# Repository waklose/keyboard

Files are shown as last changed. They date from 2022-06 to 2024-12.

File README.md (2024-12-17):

# keyboard
This is a repository for my keyboard project. Hardware design and 3D design are both self-taught, so the first designs might leave something to be desired.

## Motivation
The motivation behind making my own keyboard was the fact that I didn't have a keyboard. And I wanted a keyboard :) In retrospect buying a keyboard would actually have been quite a lot cheaper, however there was a specific feature I wanted in my keyboard. This feature relates to the use of the thumb. In normal keyboard both thumbs are primarily used on a single button, namely the space bar. This seems a tad wasteful considering the impressive dexterity of the thumb. When using our phones on the other hand we use the thumbs for the entire keyboard. Furthermore the thumbs are pressed down sideways when pressing the space bar. A more natural usage of the thumb is pressing it inward toward the hand. This is not easily achieved in a normal keyboard, but one can take inspiration from mouses with thumb buttons. As these utilize the thumb in a more natural way without compromising the other fingers. The goal with this project is to make a keyboard that utilizes the entire hand in an efficient and comfortable way. Mostly this will entail creating a design with a natural responsibility and usage of the thumb, while keeping standard usage of the rest of the hand.

## v1
This is a onehanded ergonomical hotswappable mechanical keyboard. Lots of nice adjectives, but the onehanded part is the most important. The result turned out a little bit clunky and a little unpolished, but it got the job done. More details in the dedicated folder.

## v2
Intended Additions/improvements are: backlighting, integrated microcontroller, more comfortable design, better looking design.

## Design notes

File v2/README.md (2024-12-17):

# v2
Additions/improvements are going to be: backlighting, integrated microcontroller, more comfortable design, better looking design. 

## Choice of components
* STM32F072VBT6: This is the microchip I want to use. The choice was inspired by [this](https://github.com/KoBussLLC/grabert-hardware) tutorial. The important part is that it has 87 I/Os and it has a 48 MHz internal oscillator. Thus a keyboard matrix with diodes and an external oscillator is not neccesary, which reduces the amount of components on the pcb.
* WS2812B-2020: This is the RGB LED I will use for the keyboard backlighting. There was tree main reasons for choosing this component. The first reason is the fact that it has an integrated decoupling capacitor, which reduces the amount of components on the pcb. The second reason is that it is an intelligent control LED which means that all LEDs can be controlled by a single port on the microcontroller. Lastly the input voltage on this chip can be as low as 2.7V. Which works very well with the chosen STM32F072VBT6 chip that normally uses VDD=3.3V.

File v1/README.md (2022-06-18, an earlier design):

# v1
This is my first attempt at making a onehanded keyboard. It mostly worked as expected, see [Bugs](#Bugs). 

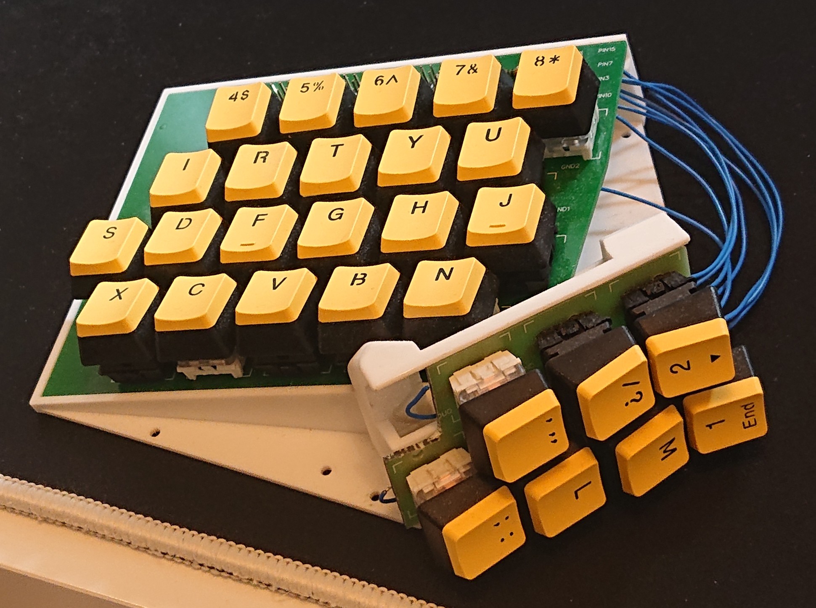
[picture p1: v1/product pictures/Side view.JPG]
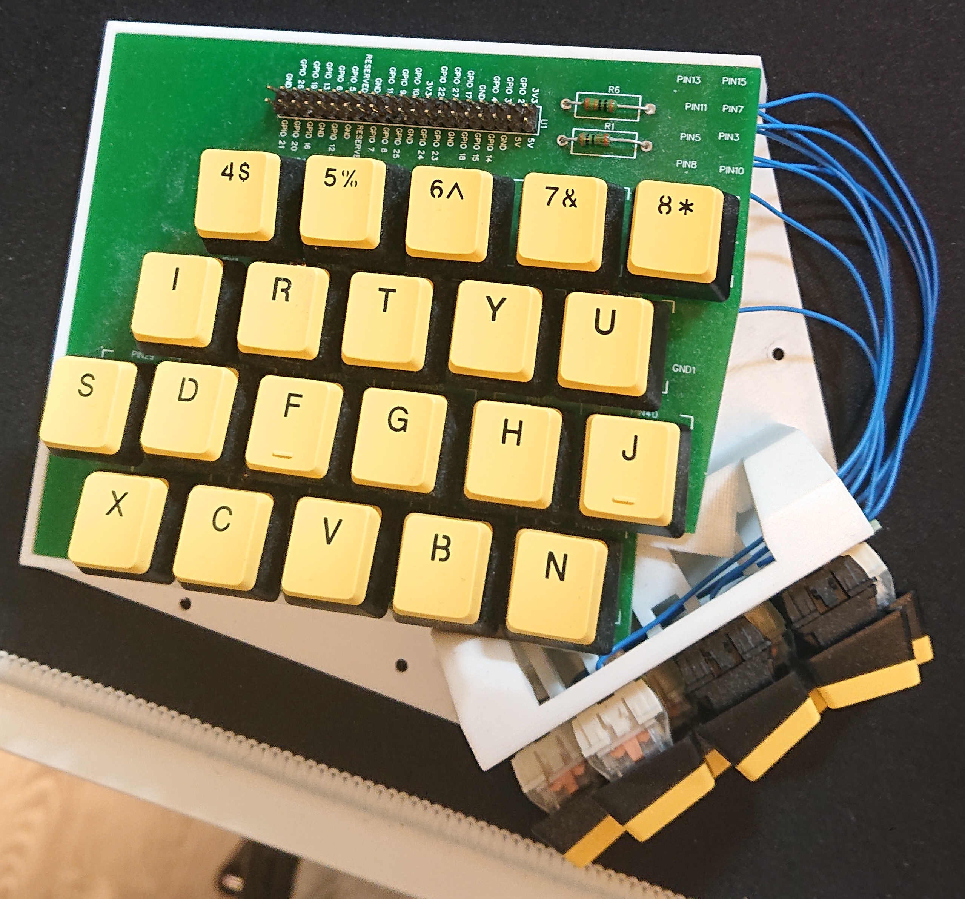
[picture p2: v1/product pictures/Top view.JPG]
 

## frame
3D objects and corresponding gcode files for case and plate are in the folder *frame*. *Fusion 360* and *PrusaSlicer* was used to design these. The print was produced at [*Omega Verksted*](https://www.omegav.ntnu.no/) at NTNU.

## pcb
The pcb and corresponding schematic are in the *pcb* folder. *EasyEDA* was used to create these. 
The pcb was ordered from [JLCPCB](https://jlcpcb.com/), and the components and connections were soldered by hand.

## Code
* The raspberry pi 4 was configured as a keyboard using [this](https://randomnerdtutorials.com/raspberry-pi-zero-usb-keyboard-hid/) online tutorial.
* The code was written in python and it is not appended. It was a very simple while true loop. It did not handle *switch bounce* in any way, however this did not turn out to be a problem.

## Choice of components
* **Raspberry pi 4**: A small computer in and of itself, so it's definitely way stronger than needed. I used it simply because I had one at hand, and it is connected to the pcb via a flat cable so it can still be disconnected and used for other projects. A simple microcontroller such as the *Arduino Pro Micro* would be a more reasonable choice. However the microchip (ATmega32U4) has fewer gpio ports and would require me to make a standard keyboard matrix. Which would require a diode for every switch in order to avoid ghosting. It seemed simpler use a controller with more gpio ports.
* **Kailh hotswap sockets**: In order to make the keyboard hotswappable, such that switches easily can be changed.
* **Cherry mx silver / Cherry mx red / Kailh silver**: These are the different switches I used. Kailh silver and Cherry mx silver are very similar and was used interchangeably. All of them are linear switches. The silver switches has quite short pre travel, which in some cases caused misclicks on the buttons where my fingers rested. Thus I used cherry mx red on these buttons instead.
* **1k resistor**: in order to protect the raspberry pi from a short in the case of faulty code.

## Bugs
* **Button not working properly**: The button connected to GPIO 2 only works a part of the time. This is likely because of a slight oversight on my part. Both GPIO 2 and 3 are pysically connected to 1.8k unchangable pull-up resistors, which are lower values than the default. This is problematic because pressing the switch creates a connection to ground with a 1k resistor (which was added for protection). Thus it is definetely closer to logical zero but still not sufficiently close to work consistently. A possible fix is to remove or reduce the 1k resistor.

## Improvements
* **Comfortable thumb buttons**: The angles of the case were not the most comfortable. A big part of the problem was that pressing the thumb buttons sideways resulted in a sideways force, which resulted in displacement and/ord rotation of the keyboard. The thumb buttons could also have had angles closer to 90 degree along the xy-axis.
* **Comfortable hand position**: A wrist rest could be integrated into the case.
* **General design**: The design ended up looking very clunky and it was also very impractical to move around. The main problem is the fact that the raspberry pi 4 is connected to the keyboard via a flat cable. Adding a microchip to the pcb is the obvious solution.

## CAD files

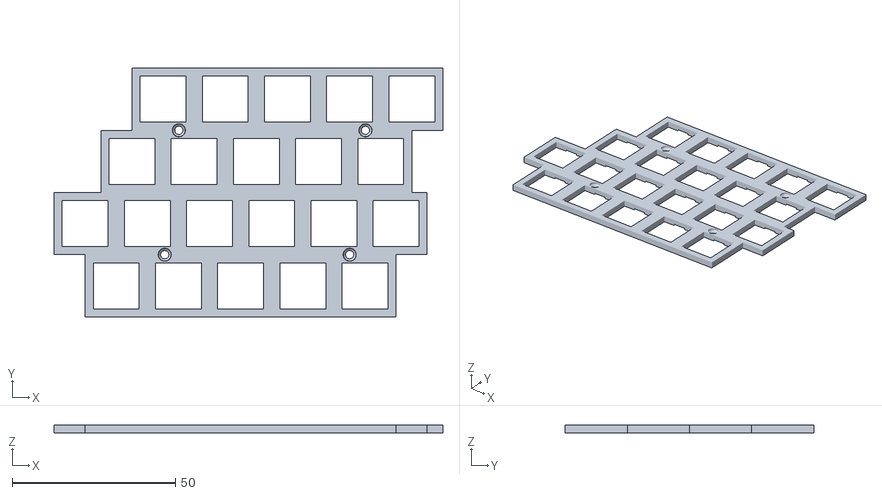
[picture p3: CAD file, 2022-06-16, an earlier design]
v1/frame/plate_main.stl
119.1 x 76.2 x 2.40

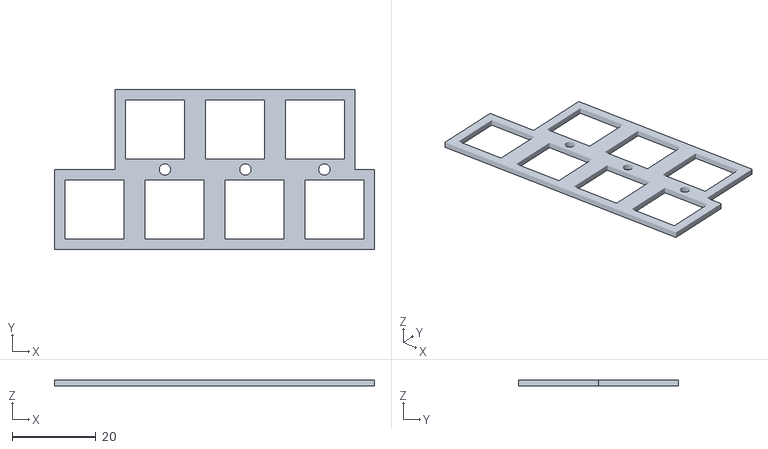
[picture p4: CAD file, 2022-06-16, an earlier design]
v1/frame/plate_thumbButtons.stl
76.2 x 38.1 x 1.50

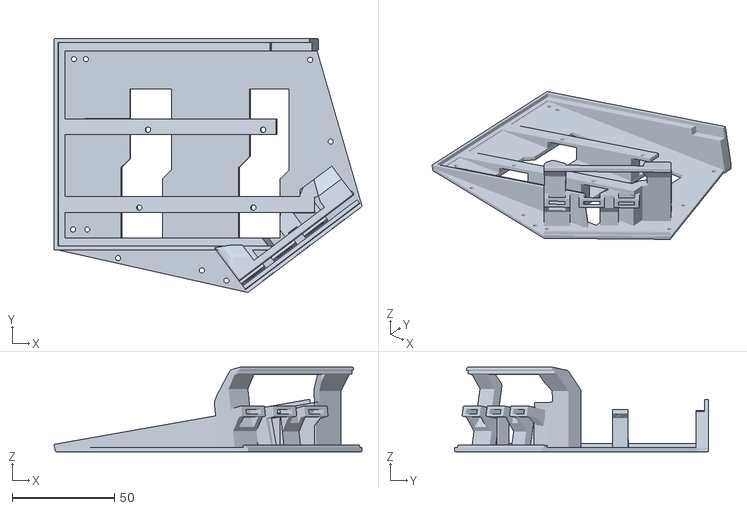
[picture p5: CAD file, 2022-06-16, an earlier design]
v1/frame/case.stl
150.6 x 124.2 x 41.3

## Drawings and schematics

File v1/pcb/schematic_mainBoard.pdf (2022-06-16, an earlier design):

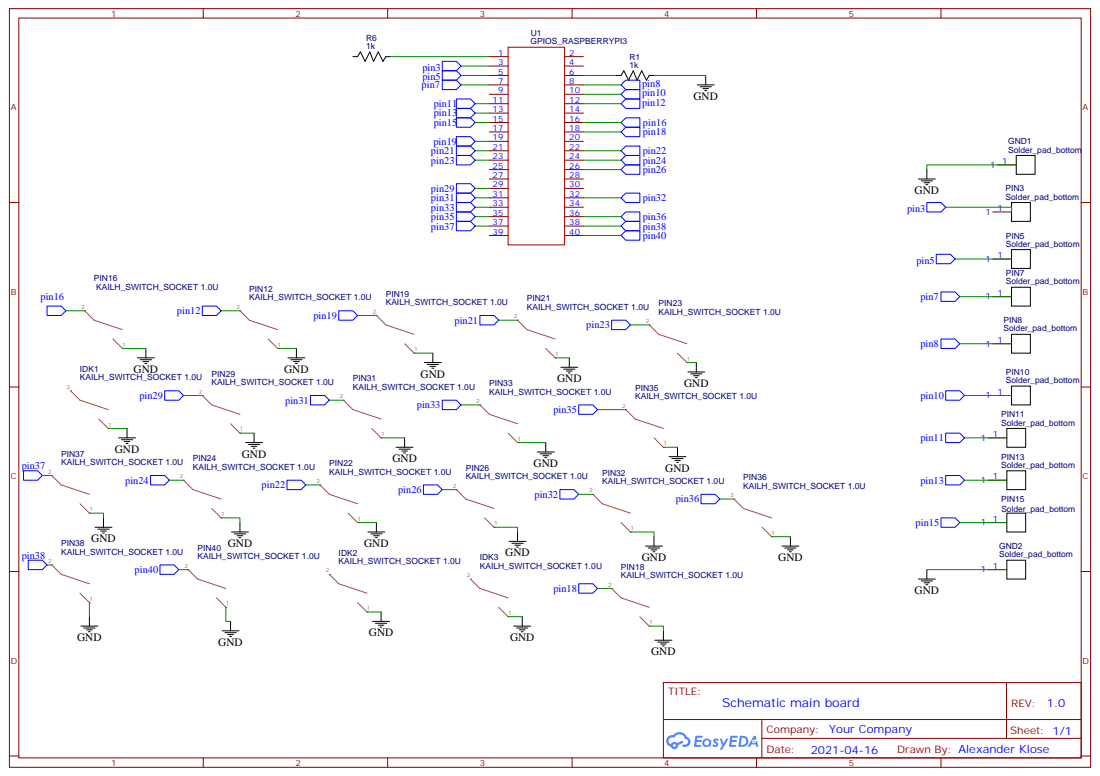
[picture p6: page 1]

Drawn By: Alexander Klose

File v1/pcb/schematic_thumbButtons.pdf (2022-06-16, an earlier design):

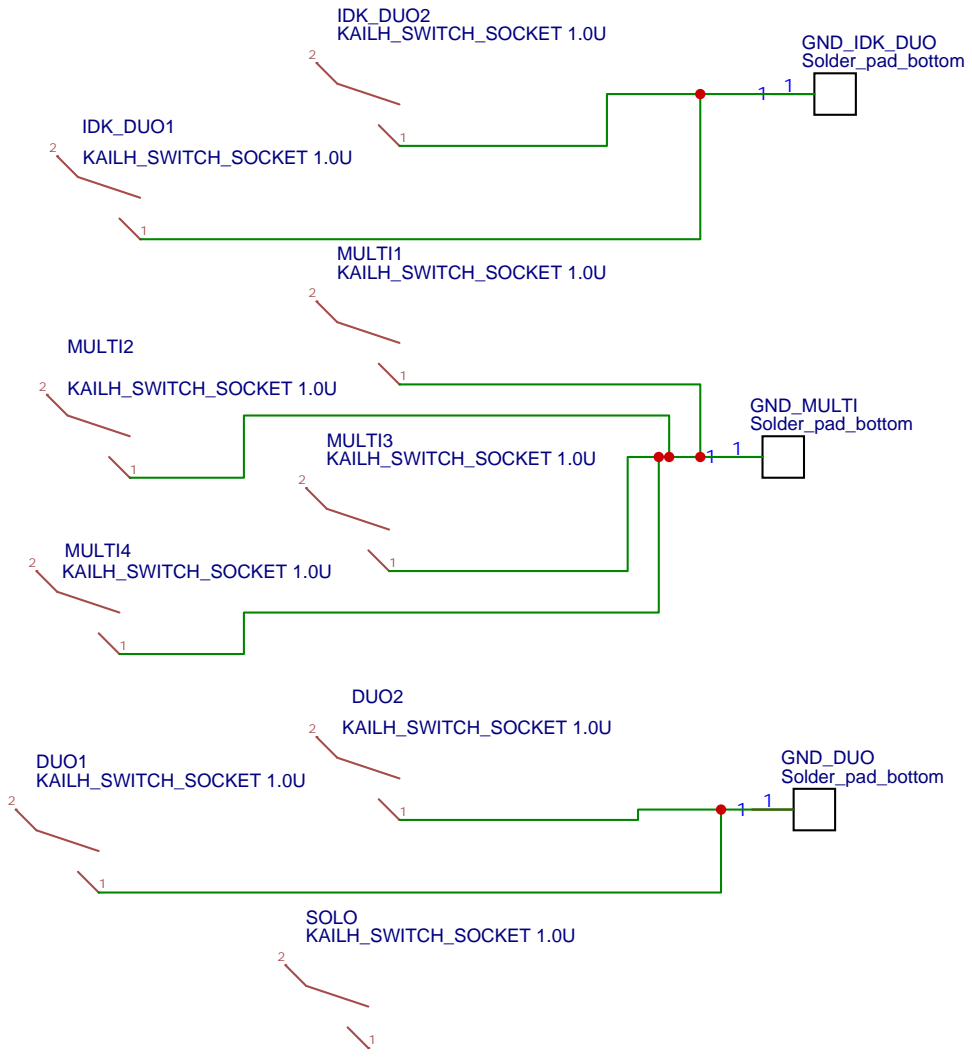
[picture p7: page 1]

Drawn By: Alexander Klose

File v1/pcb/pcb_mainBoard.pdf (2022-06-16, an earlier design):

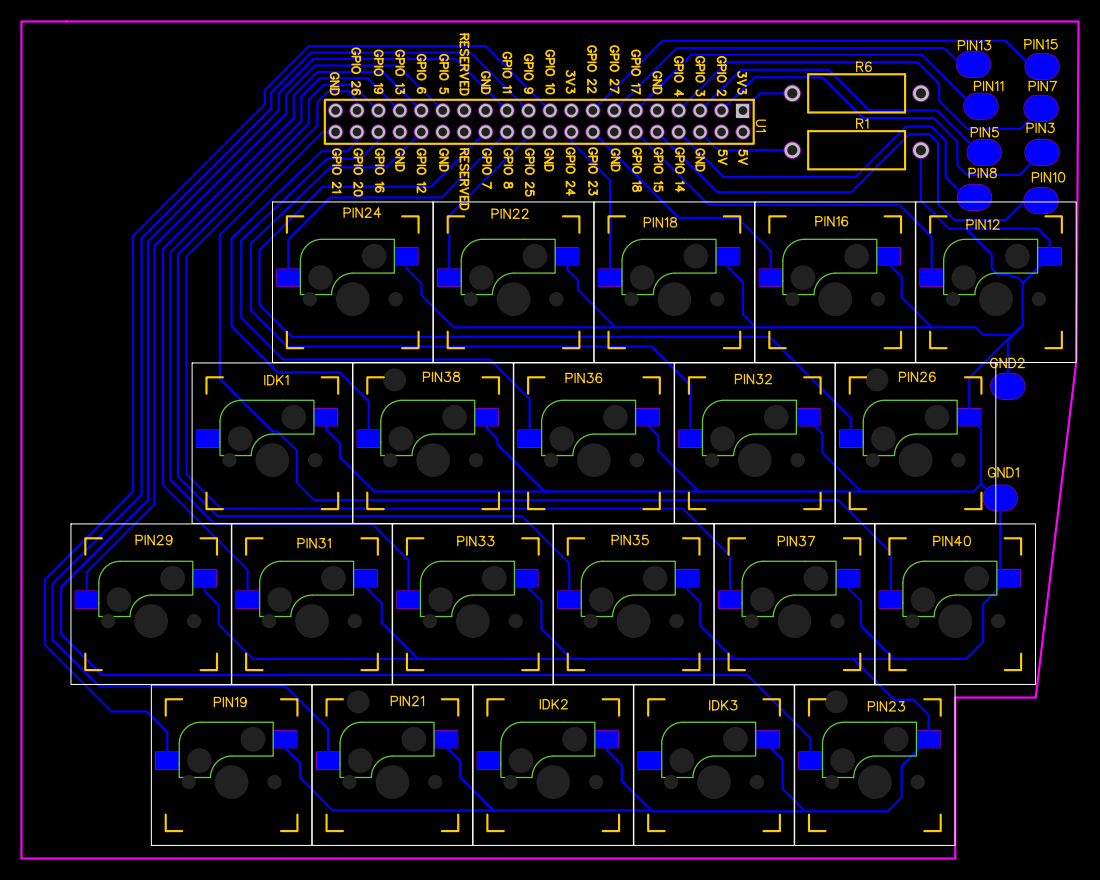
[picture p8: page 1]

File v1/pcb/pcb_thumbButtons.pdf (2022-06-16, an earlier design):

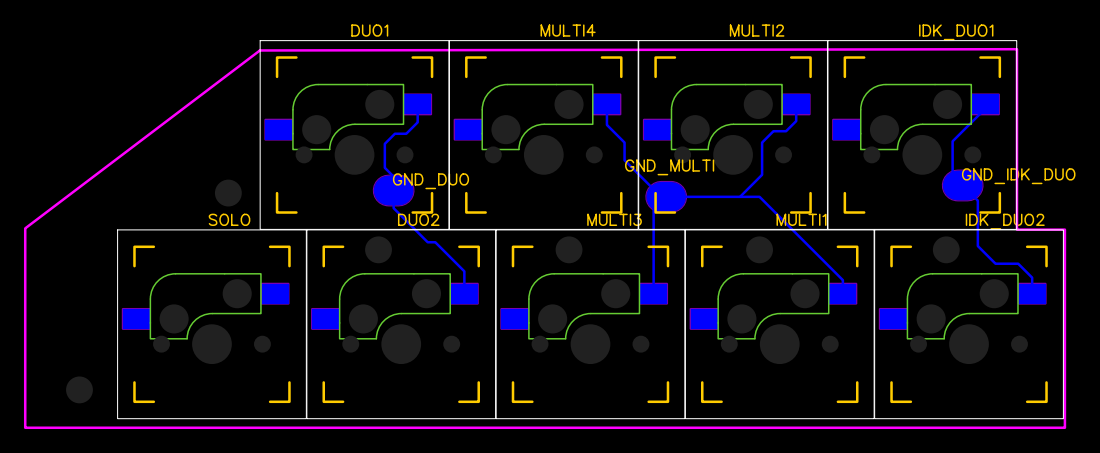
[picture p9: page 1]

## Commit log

2022-06-16 uploading prototype
    [case.stl, plate_main.stl, plate_thumbButtons.stl]
2022-06-16 name change, I considered it a v1 when I made it. Looking at it now it looks more like a prototype, but v1 seems more correct.
    [case.stl, plate_main.stl, plate_thumbButtons.stl]
